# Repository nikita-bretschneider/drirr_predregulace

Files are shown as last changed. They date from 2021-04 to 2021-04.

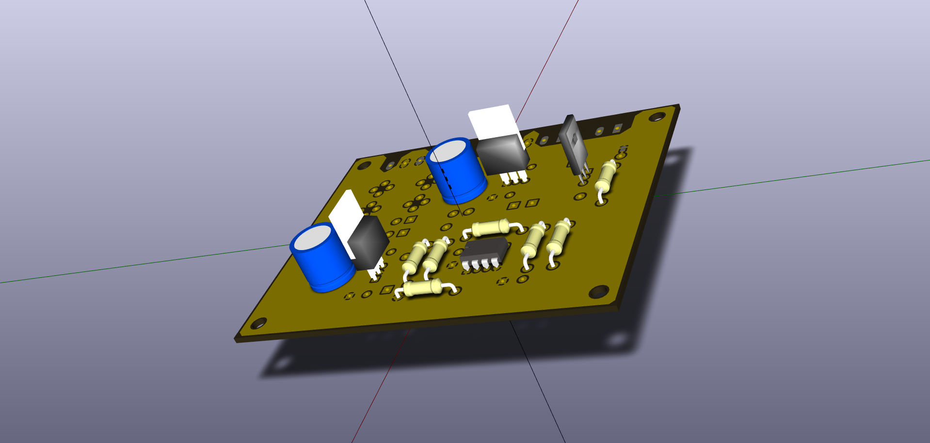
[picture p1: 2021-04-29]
3D/drirr_predreg1.png

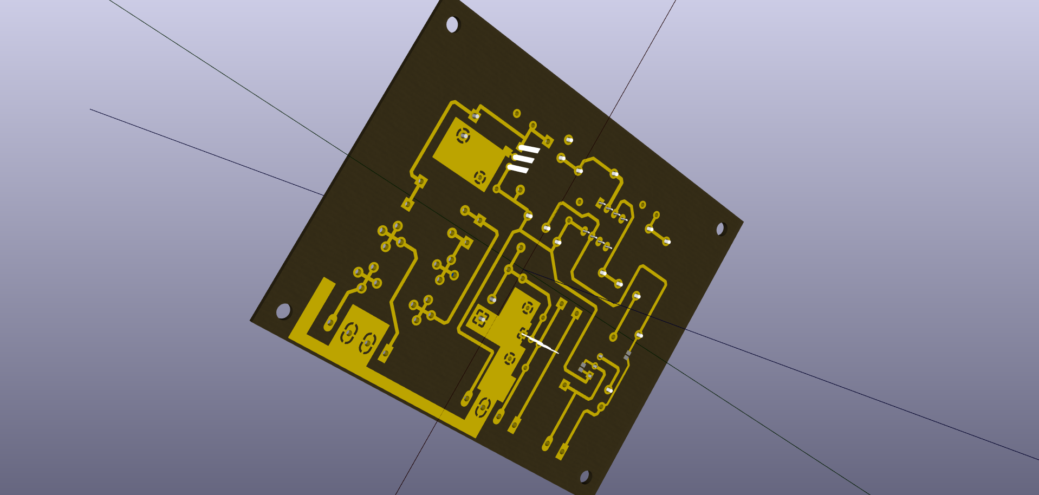
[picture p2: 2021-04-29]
3D/drirr_predreg4.png

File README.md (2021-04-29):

# Poznámky k návrhu desky skokové předregulace

## Změny v konstrukci

Konstrukce není moje. Hodnoty součástek jsou uvedeny pouze tam, kde byly známy (platí pro schéma i silkscreeny). Jediná konstrukční změna je přidání tranzistoru *Q1*, protože proudová zatížitelnost výstupu *LM311* je pouze *50mA*, což stačí na malé relé, avšak chci otevřít možnost použít automobilní relé, jehož pozitivní vlastností je že se nerozteče při trvalém sepnutí. Bohužel si dokáže vzít až *140mA*. PNP tranzistor používám z toho důvodu, aby nebylo nutno měnit logiku spínání. *LM311* sama o sobě spíná v záporném pólu, pokud se aktivuje spínání tranzistorem, spíná se v kladném pólu, vlastní *LM311* spíná pouze bázový proud tranzistoru *Q1*. Použití tohoto tranzistoru je optional a konfiguruje se při osazení propojkami *J4*, *J5* a *J6*. Původní zapojení, tj. bez tranzistoru *Q1*, se aktivuje neosazením *Q1* a *R6*, dále se spojí *J5* a *J6*. Propojka *J4* zůstává rozpojená. Pro použití tranzistoru *Q1* (například při použití automobilního relé) se osadí *R6*, *Q1* a propojí se propojka *J4*. Propojky *J5* a *J6* zůstávají rozpojené.

## Použití pojmenovaných signálů a propojovací definice

Použití pojmenovaných signálů umožňuje rozdělit schéma do funkčních bloků a tak jej zpřehlednit. Separátní definice připojovacích míst k signálům umožňuje snadno měnit pinout jednotlivých konektorů s ohledem na situaci na desce, neb docházelo k optimalizaci na snadnou výrobu a minimální cenu desky. Dále takový postup vytváří přehledný pinout všech použitých konektorů na jediném místě dokumentace, což opět poslouží přehlednosti.

## Vlastní návrh desky, možné problémy, prokovy

Vlastní návrh desky je proveden tak, aby byl výrobně jednoduchý. Desku lze nechat vyrobit jak s prokovy tak bez nich. V obou případech lze za slabé místo považovat kondenzátory *C1* a *C2*, kde je jeden z pólů přístupný do rozlité země (vedení *ACS0*) pouze přes prokov. Vzhledem k zátěži celého pomocného zdroje řádově ve stovkách mA (a z toho plynoucích cirkulačních proudů maximálně ve stovkách mA) to nepovažuji za problém. Větší problém nastává při pájení *C1* a *C2* do desky bez prokovů, kde nelze pájet z horní strany kvůli překrytí vrstvý pouzdrem součástky. Pro tento případ je na spodní straně připravena rozlitá plocha mědi, kdy lze provést propojení s vrchní stranou (stranou součástek) pomocí vývodů jiných součástek, případně na vhodném místě navrtat via.

Desku lze též vyrobit svépomocí, kdy se strana spojů vyrobí například metodou *toner transfer*, přičemž horní strana obsahuje toliko rozlitou měď (s vyjímkou jednoho jumperu, který lze ignorovat, viz níže), čili před leptáním se vykryjí problematická místa (pod pojistkami a pod částmi konektorů) lakýrnickou páskou, celou horní strana se poté přestříká leptuvzdorným lakem a po zaschnutí se odstraní lakýrnická páska. Pro spodní stranu se použije buď metoda toner transfer, nebo fotocesta. V případě toner transferu doporučuji začít spodní stranou, v případě fotocesty doporučuji obrácený postup.  Po odleptání a odvrtání ze spodní strany se z horní  strany následně odstraní měděná plocha v okolí děr buď odfrézováním, nebo zcela jednoduše pomocí mělkého odvrtání tlustým vrtákem. Neodvrtávají se místa, kde je součástka spojena se zemní plochou. V těchto místech se potom pájí z obou stran. Problémem jednoduché výroby je jumper *J4*, který  je ze stramy součástek a při prostém ponechání měděné vrstvy jednoduše nebude existovat. Nepovažuji to však za problém, protože konfigurace se provádí při osazení a později ji již není možné změnit, čili pokud se osazuje *Q1*, potom se neodfrézuje/neodvrtá měděná vrstva kolem anody *D8* a tato se připájí z obou stran. *J6* a *J5* se potom neosazuje. V opačném případě se okolí anody *D8* odfrézuje, *Q1* a *R6* se neosadí, *D8* se zapájí jen z jedné strany a propojí se *J6* a *J5*.

## Proč není na desce relé

Protože otevřenost variabilitě, protože míním použít automobilní relé, které má vlastní držák a vývody na fastonech, v neposlední řadě proto, že se tím zmenší deska. Navíc to vytváří určitou variabilitu v zapojení předregulace, tj. lze například přepínat mezi dvoucestným usměrněním a násobičem, což otevírá možnost použít transformátor, který náhodou máte, namísto nákupu nějakého konkrétního. Celá deska je navrhovaná s ohledem na maximální možnou variabilitu, je zcela nevhodná pro seriovou výrobu včetně maloseriové, takže je pochopitelně nevhodná i pro strojové osazení.

## Proč se používají svorkovnice

V původní konstrukci byly fastony a osobně v nich vidím problém. Ten konektor chce značnou sílu pro zapojení i vypojení, přičemž tato deska byla navrhovaná nejen na maximální variabilitu, ale také na možnost snadné výroby, do které musím bohužel zahrnout nejen pochybné lamináty, ale též kuprokart a jiné hrůzy. Kombinace kuprokartu a fastonu znamená zlomenou desku. Spolehlivě. Svorkovnice ale funguje, protože se na desku příliš netlačí. Pochopitelně na jejím místě lze osadit víceméně leccos, co roztečí odpovídá. Svorkovnice jsou na desce dvě čtyřpólové a jedna dvoupólová. Spojit je všechny do jedné velké svorkovnice není dobrý nápad, toner transfer občas způsobí mírné ujetí rozměrů, což by pro tak velký pevný kus bylo fatální. Svorkovice je tedy rozdělena na tři logické části — propojení s řídící deskou zdroje, čili pomocné napájení *±12V* a *sense* vstup, svorkovnici pro připojení cívky relé a svorkovnici pro připojení pomocného transformátoru. Tato je zvolena čtyřpinová ze dvou důvodů. Především dvoupinové svorkovnice lze stohovat na čtyřpólové, takže tato volba znamená, že koupíte pět dvoupólových (a dostanete množstevní slevu, což by vás při nákupu jedné třípólové nepotkalo), dále transformátor může mít dvě oddělená sekundární vinutí, proto je střed vyveden dvakrát.

## Použití pomocného transformátoru s jediným sekundárním vinutím

Pokud máte pomocný transformátor jen s jediným vinutím bez vyvedeného středu, neosadí se *F1*, *D1*, *D4* a polovina svorkovnice *J3*. Dále je nutno zvětšit kapacity *C1* a *C2* na minimálně dvojnásobek.Transformátor potom pracuje v lichých půlvlnách do jedné větve a v sudých do druhé. Toto řešení však příliš nedoporučuji.

## Závěr, varování

Konstrukce není moje, desky nevyrábím, pokud si někde chcete zadat výrobu, je to váš problém, odmítám za to nést jakoukoliv odpovědnost. Chyby se stávají, to je realita. Vše si důkladně zkontrolujte a rozmyslete před tím, než začnete desku vyrábět.

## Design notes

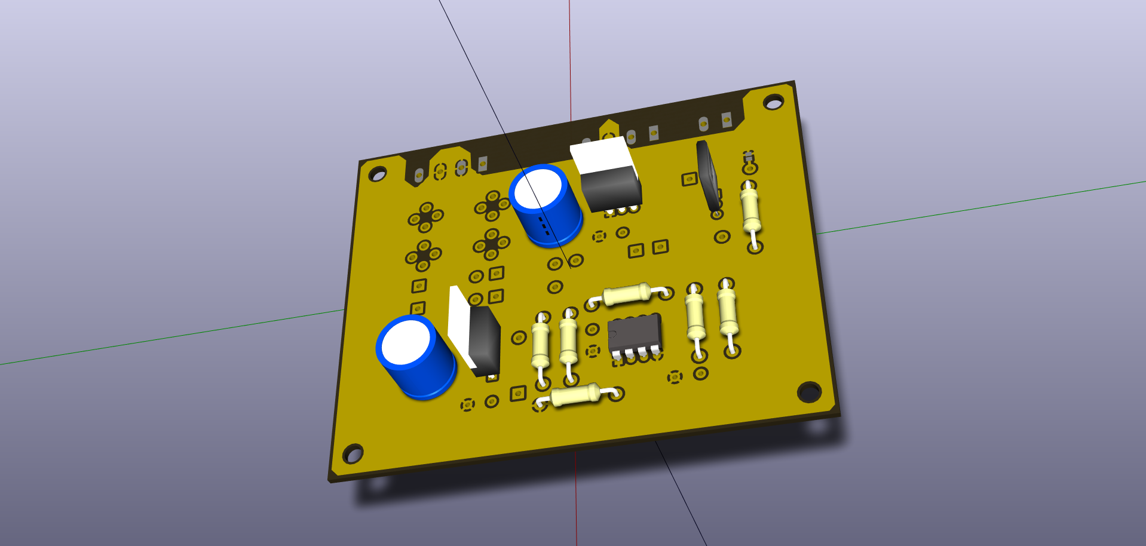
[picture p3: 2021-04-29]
3D/drirr_predreg2.png

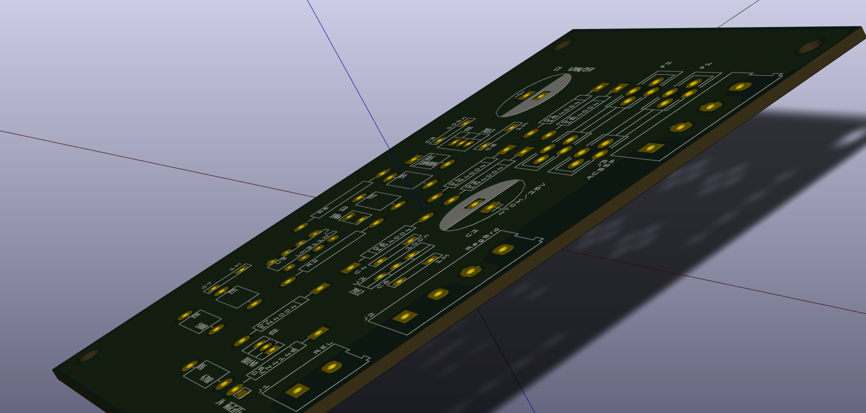
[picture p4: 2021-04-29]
3D/drirr_predregA.png

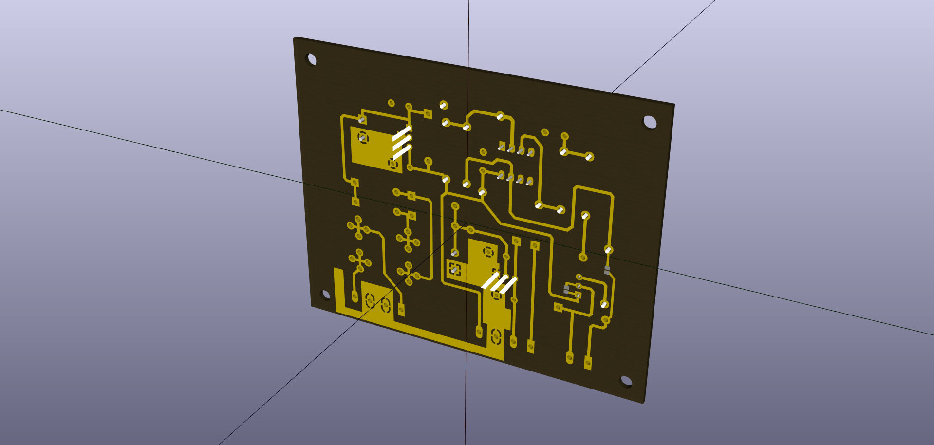
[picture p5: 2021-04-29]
3D/drirr_predreg3.png

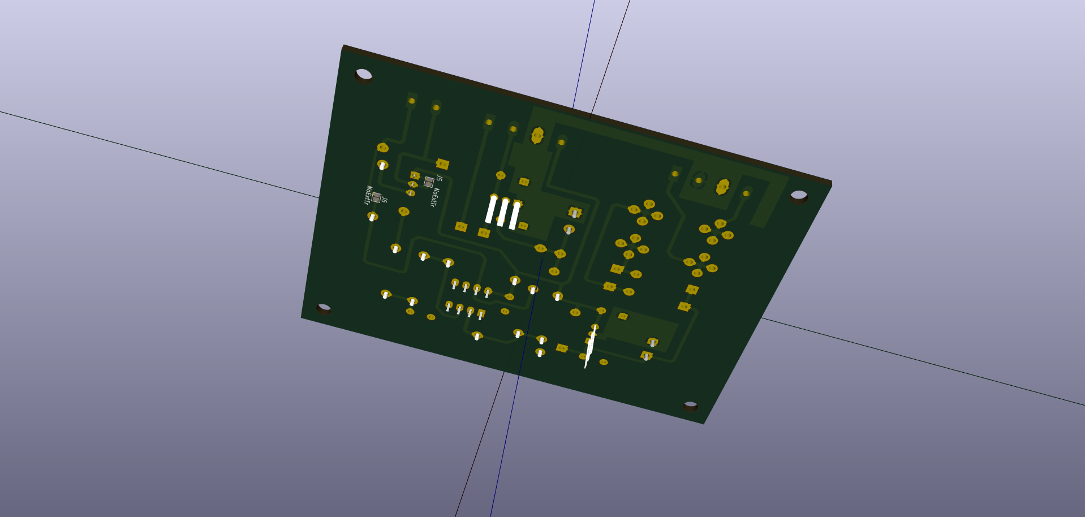
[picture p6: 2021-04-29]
3D/drirr_predreg7.png

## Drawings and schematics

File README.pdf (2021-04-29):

# Poznámky k návrhu desky skokové předregulace

# Změny v konstrukci

Konstrukce není moje. Hodnoty součástek jsou uvedeny pouze tam, kde byly známy (platí pro schéma i silkscreeny). Jediná konstrukční změna je přidání tranzistoru Q1, protože proudová zatížitelnost výstupu LM311 je pouze 50mA, což stačí na malé relé, avšak chci otevřít možnost použít automobilní relé, jehož pozitivní vlastností je že se nerozteče při trvalém sepnutí. Bohužel si dokáže vzít až 140mA. PNP tranzistor používám z toho důvodu, aby nebylo nutno měnit logiku spínání. LM311 sama o sobě spíná v záporném pólu, pokud se aktivuje spínání tranzistorem, spíná se v kladném pólu, vlastní LM311 spíná pouze bázový proud tranzistoru Q1. Použití tohoto tranzistoru je optional a konfiguruje se při osazení propojkami J4, J5 a J6. Původní zapojení, tj. bez tranzistoru Q1, se aktivuje neosazením Q1 a R6, dále se spojí J5 a J6. Propojka J4 zůstává rozpojená. Pro použití tranzistoru Q1 (například při použití automobilního relé) se osadí R6, Q1 a propojí se propojka J4. Propojky J5 a J6 zůstávají rozpojené.

# Použití pojmenovaných signálů a propojovací definice

Použití pojmenovaných signálů umožňuje rozdělit schéma do funkčních bloků a tak jej zpřehlednit. Separátní definice připojovacích míst k signálům umožňuje snadno měnit pinout jednotlivých konektorů s ohledem na situaci na desce, neb docházelo k optimalizaci na snadnou výrobu a minimální cenu desky. Dále takový postup vytváří přehledný pinout všech použitých konektorů na jediném místě dokumentace, což opět poslouží přehlednosti.

# Vlastní návrh desky, možné problémy, prokovy

Vlastní návrh desky je proveden tak, aby byl výrobně jednoduchý. Desku lze nechat vyrobit jak s prokovy tak bez nich. V obou případech lze za slabé místo považovat kondenzátory C1 a C2, kde je jeden z pólů přístupný do rozlité země (vedení ACS0) pouze přes prokov. Vzhledem k zátěži celého pomocného zdroje řádově ve stovkách mA (a z toho plynoucích cirkulačních proudů maximálně ve stovkách mA) to nepovažuji za problém. Větší problém nastává při pájení C1 a C2 do desky bez prokovů, kde nelze pájet z horní strany kvůli překrytí vrstvý pouzdrem součástky. Pro tento případ je na spodní straně připravena rozlitá plocha mědi, kdy lze provést propojení s vrchní stranou (stranou součástek) pomocí vývodů jiných součástek, případně na vhodném místě navrtat via.

Desku lze též vyrobit svépomocí, kdy se strana spojů vyrobí například metodou toner transfer, přičemž horní strana obsahuje toliko rozlitou měď (s vyjímkou jednoho jumperu, který lze ignorovat, viz níže), čili před leptáním se vykryjí problematická místa (pod pojistkami a pod částmi konektorů) lakýrnickou páskou, celou horní strana se poté přestříká leptuvzdorným lakem a po zaschnutí se odstraní lakýrnická páska. Pro spodní stranu se použije buď metoda toner transfer, nebo fotocesta. V případě toner transferu doporučuji začít spodní stranou, v případě fotocesty doporučuji obrácený postup. Po odleptání a odvrtání ze spodní strany se z horní strany následně odstraní měděná plocha v okolí děr buď odfrézováním, nebo zcela jednoduše pomocí mělkého odvrtání tlustým vrtákem. Neodvrtávají se místa, kde je součástka spojena se zemní plochou. V těchto místech se potom pájí z obou stran. Problémem jednoduché výroby je jumper J4, který je ze stramy součástek a při prostém ponechání měděné vrstvy jednoduše nebude existovat. Nepovažuji to však za problém, protože konfigurace se provádí při osazení a později ji již není možné změnit, čili pokud se osazuje Q1, potom se neodfrézuje/neodvrtá měděná vrstva kolem anody D8 a tato se připájí z obou stran. J6 a J5 se potom neosazuje. V opačném případě se okolí anody D8 odfrézuje, Q1 a R6 se neosadí, D8 se zapájí jen z jedné strany a propojí se J6 a J5.

# Proč není na desce relé

Protože otevřenost variabilitě, protože míním použít automobilní relé, které má vlastní držák a vývody na fastonech, v neposlední řadě proto, že se tím zmenší deska. Navíc to vytváří určitou variabilitu v zapojení předregulace, tj. lze například přepínat mezi dvoucestným usměrněním a násobičem, což otevírá možnost použít transformátor, který náhodou máte, namísto nákupu nějakého konkrétního. Celá deska je navrhovaná s ohledem na maximální možnou variabilitu, je zcela nevhodná pro seriovou výrobu včetně maloseriové, takže je pochopitelně nevhodná i pro strojové osazení.
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

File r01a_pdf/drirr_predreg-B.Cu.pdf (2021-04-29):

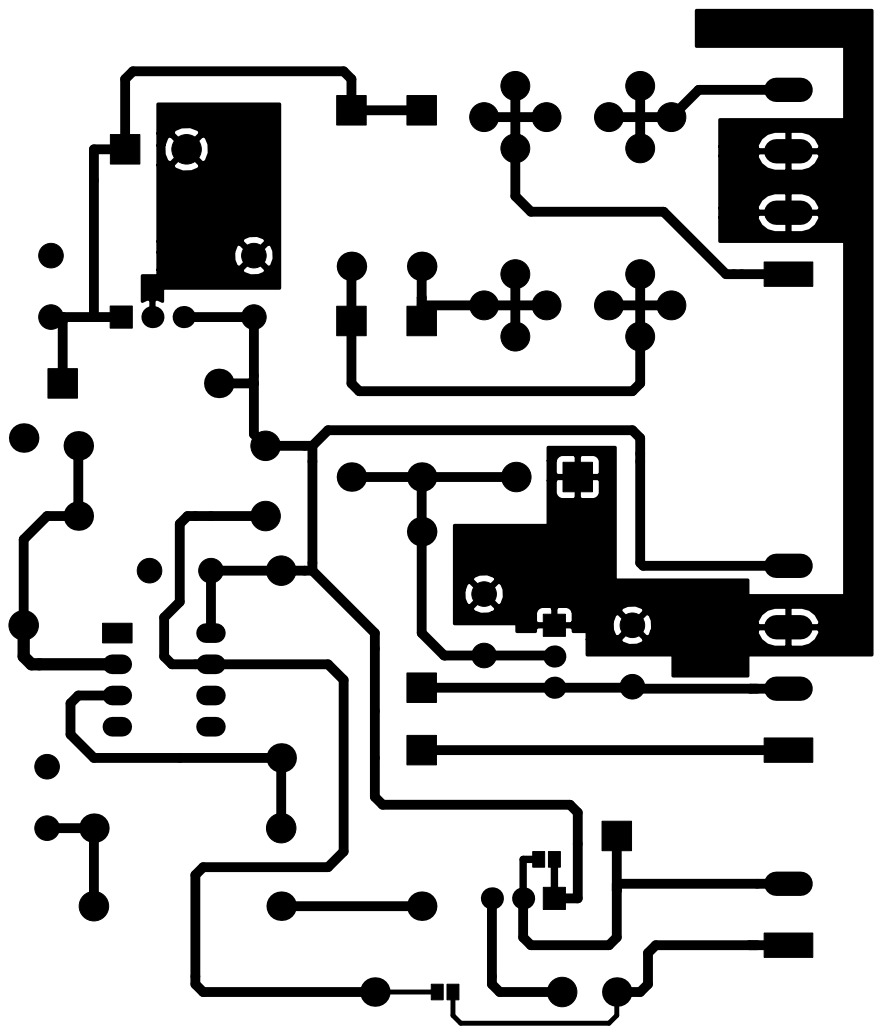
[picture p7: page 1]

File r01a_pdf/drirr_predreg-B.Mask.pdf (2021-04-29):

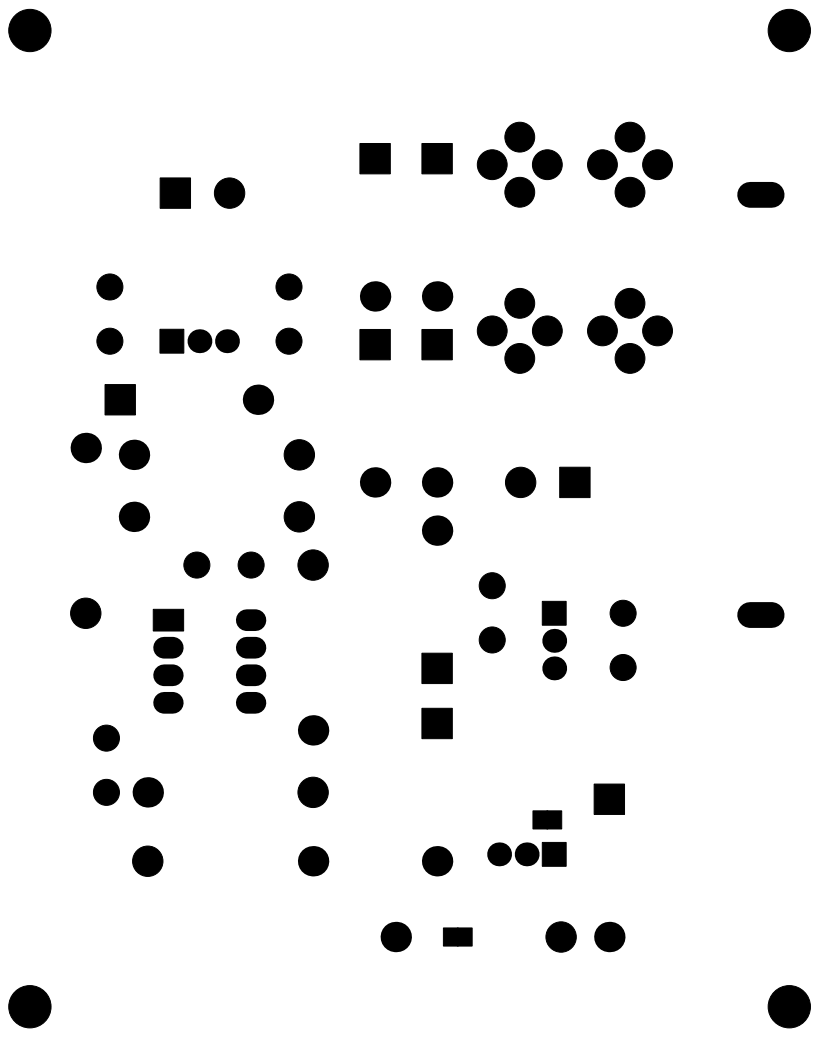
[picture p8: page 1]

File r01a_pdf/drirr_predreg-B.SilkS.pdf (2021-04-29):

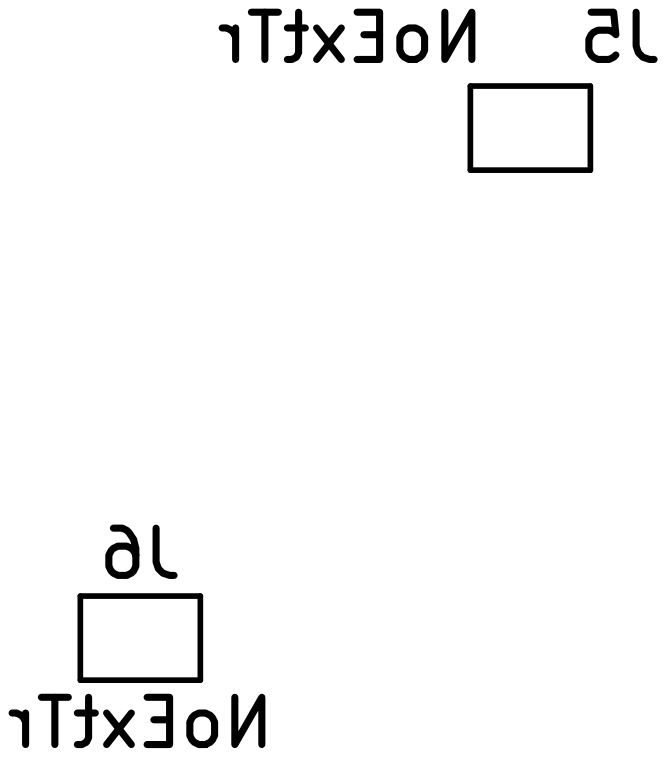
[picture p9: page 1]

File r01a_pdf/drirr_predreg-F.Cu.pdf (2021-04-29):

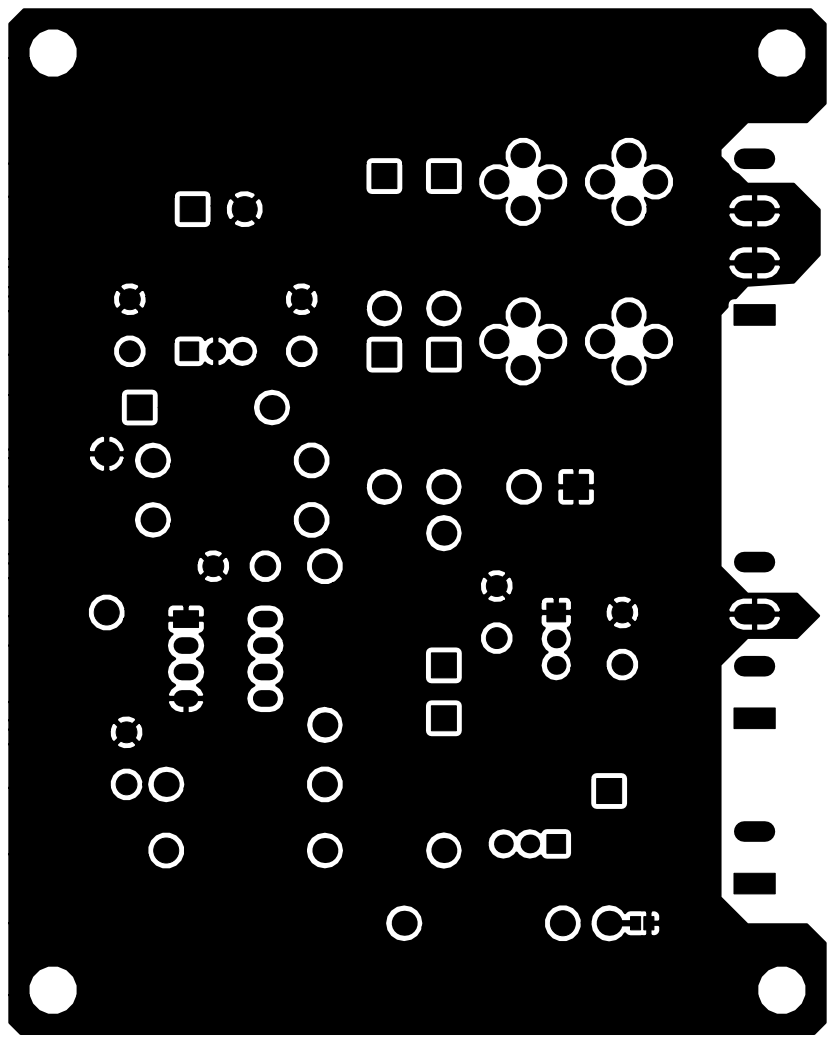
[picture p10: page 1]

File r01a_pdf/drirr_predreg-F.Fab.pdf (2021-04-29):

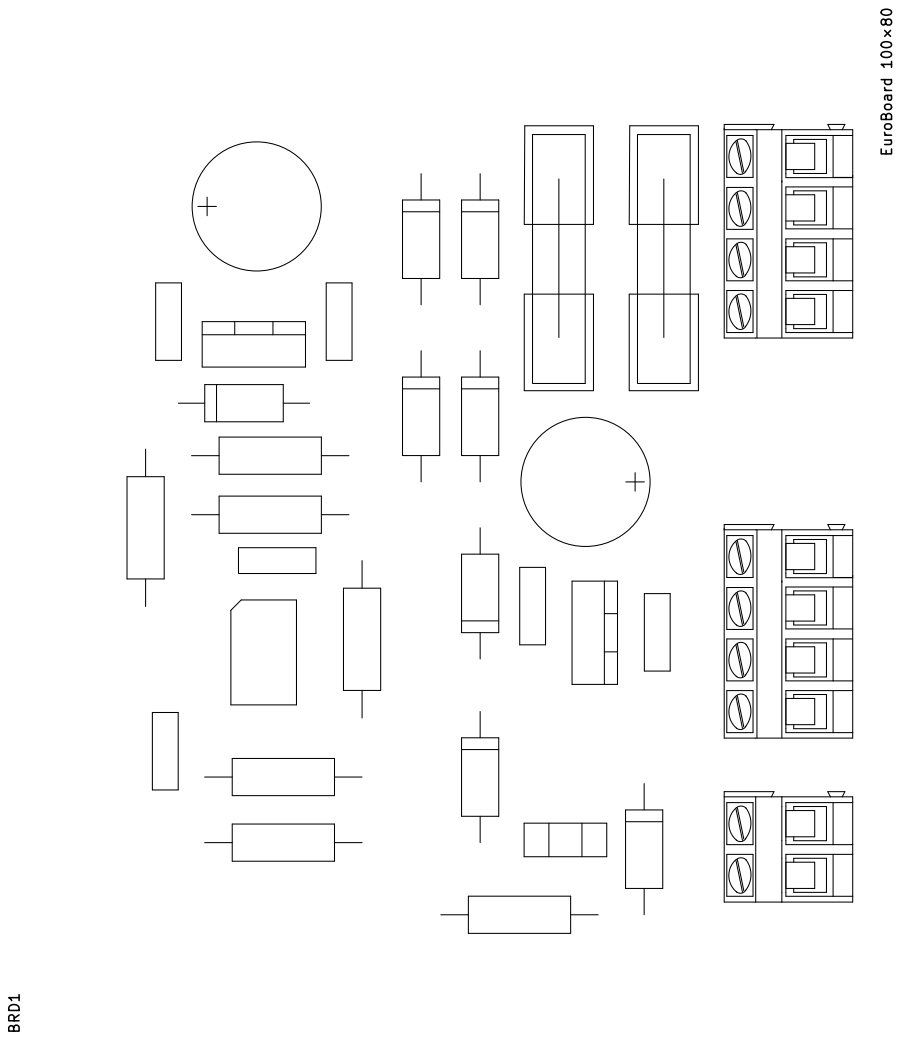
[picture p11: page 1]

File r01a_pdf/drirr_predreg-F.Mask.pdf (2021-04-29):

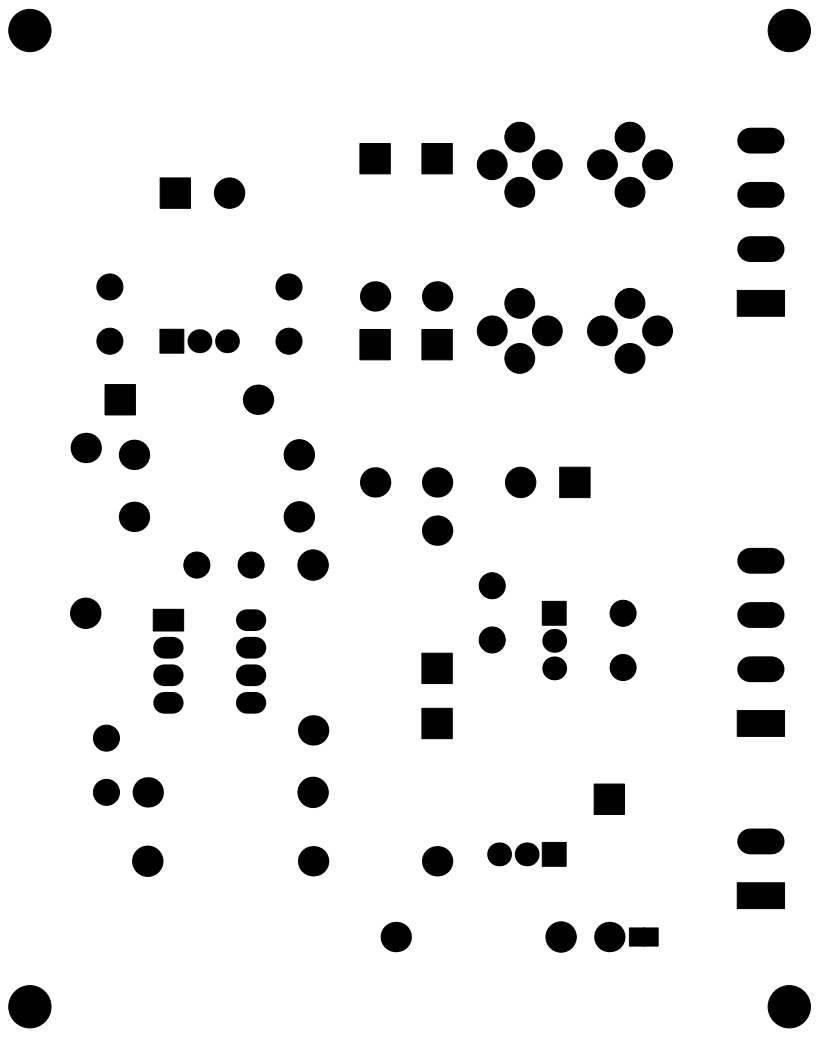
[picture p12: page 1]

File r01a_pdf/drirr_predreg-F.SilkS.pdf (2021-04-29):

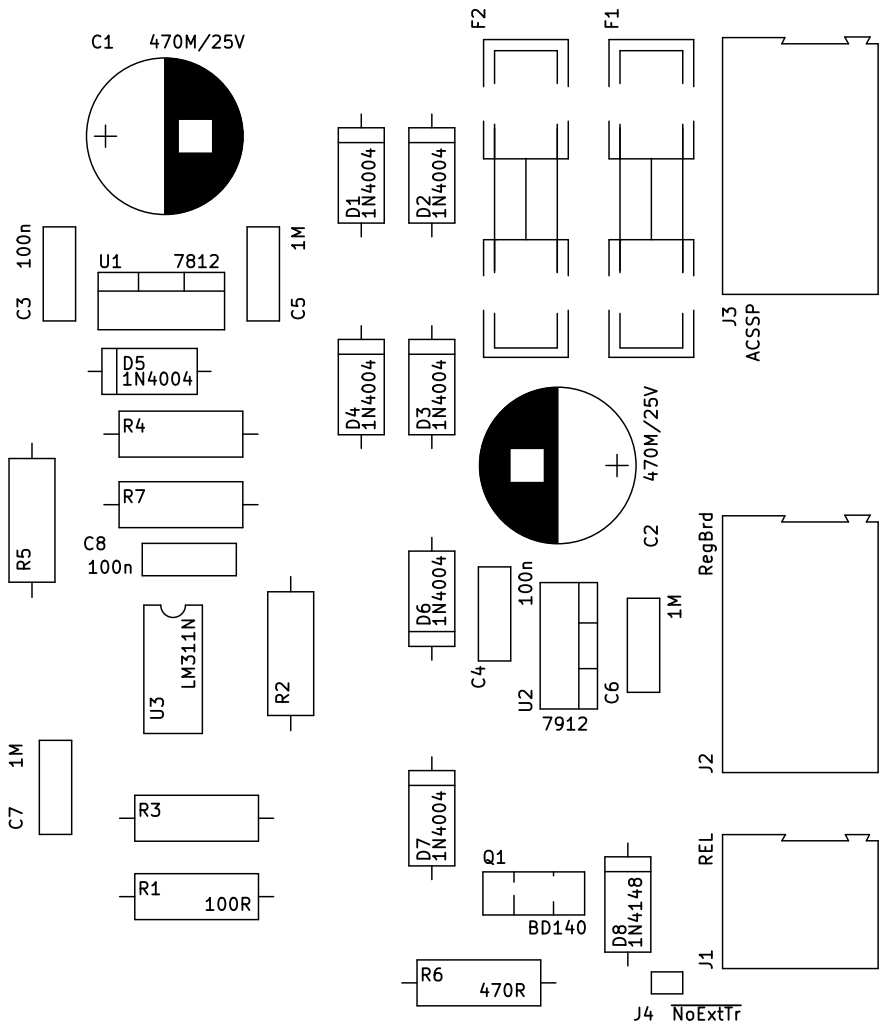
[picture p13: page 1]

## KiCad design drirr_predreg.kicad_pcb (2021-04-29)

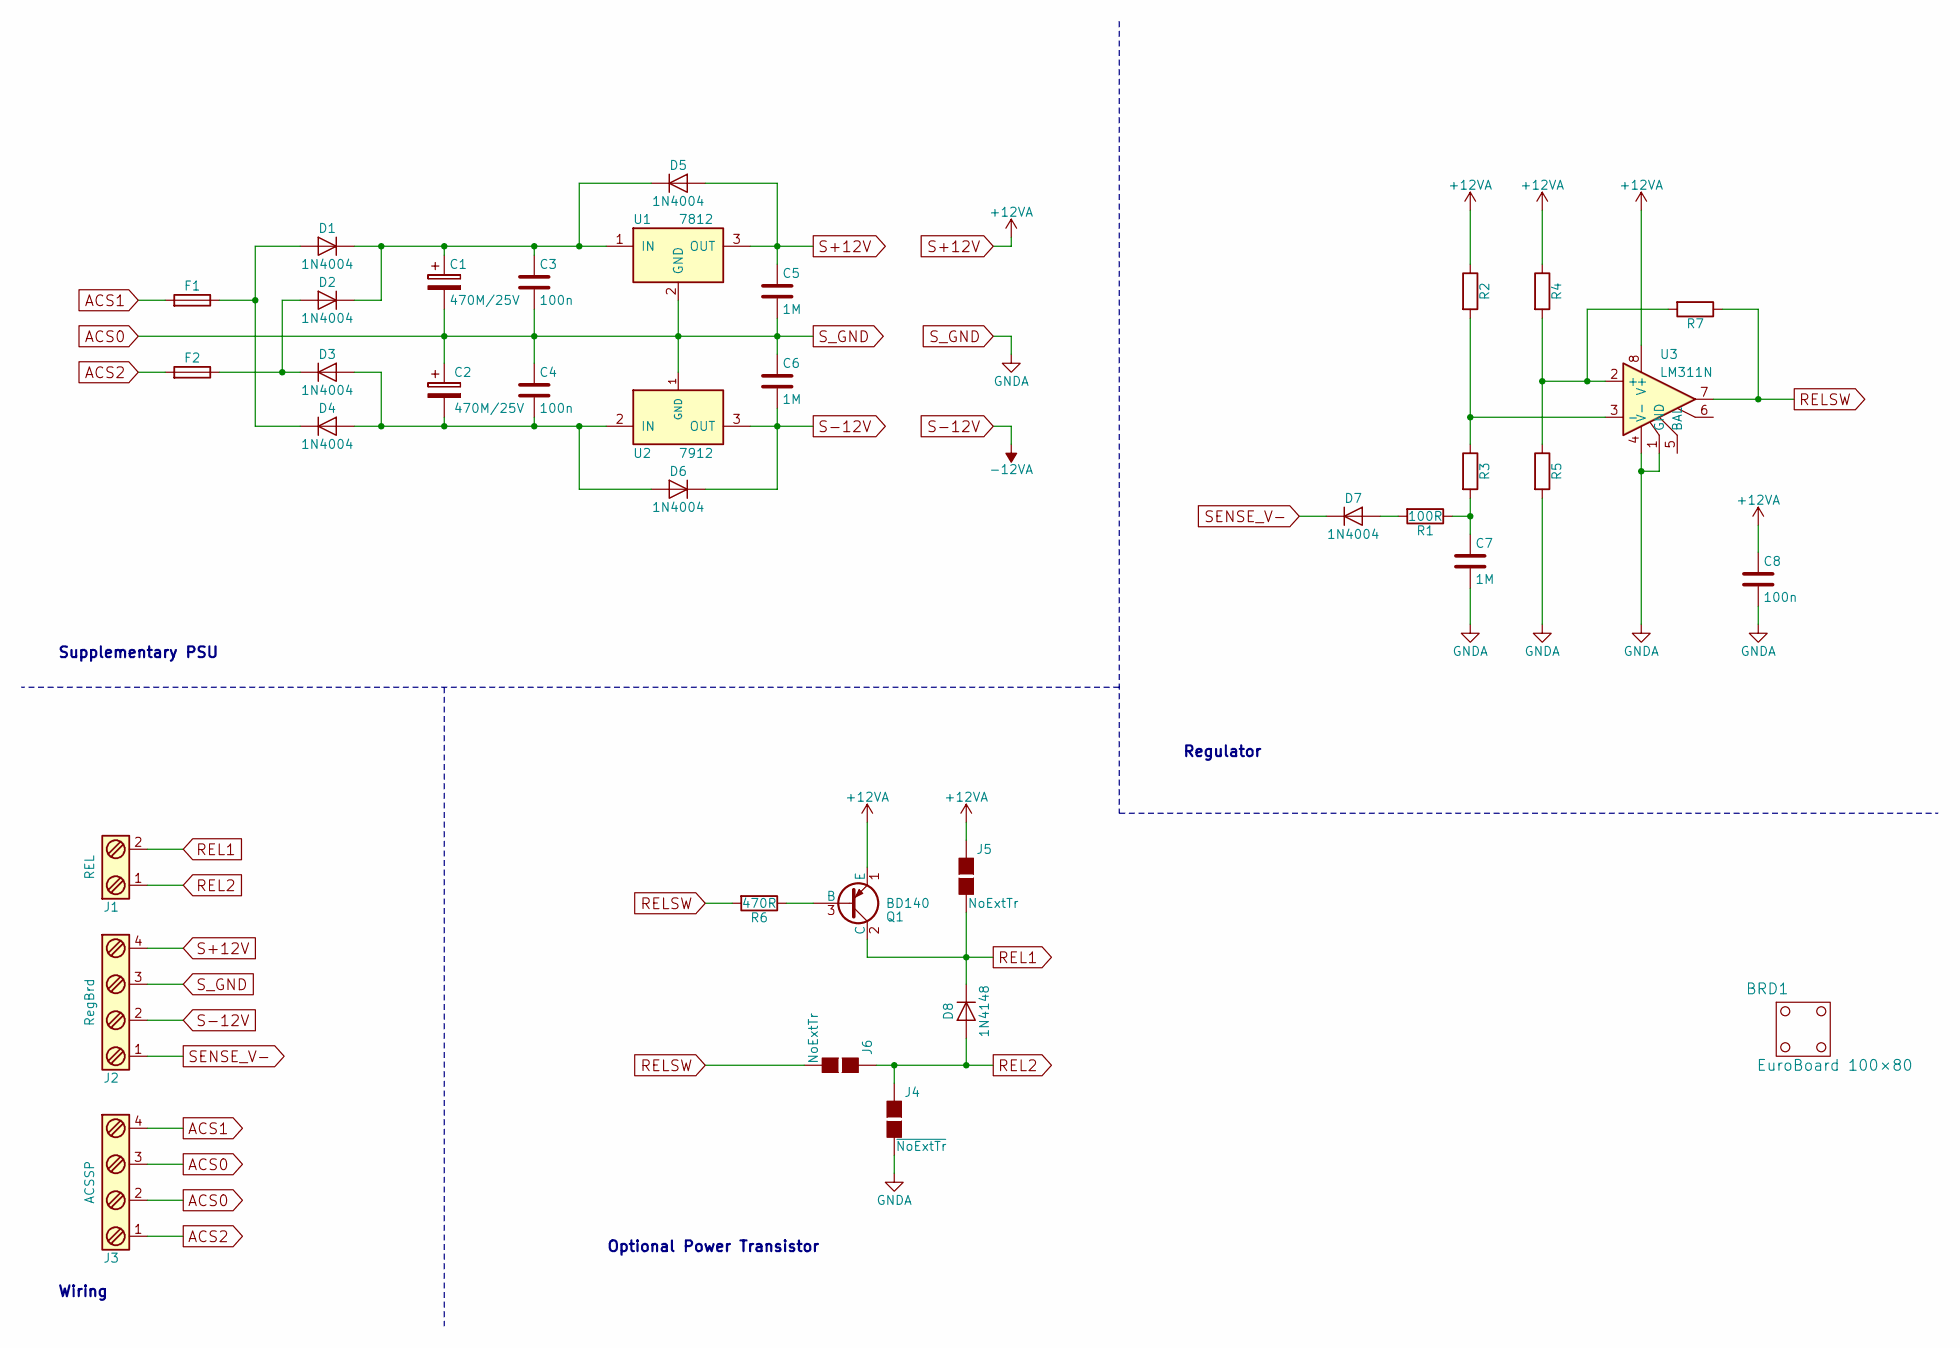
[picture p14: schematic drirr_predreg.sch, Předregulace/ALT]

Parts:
BRD1: EuroBoard 100×80; EuroBoard_halb_Type-I_100mmX80mm_holes
C1, C2: 470M/25V; CP_Radial_D12.5mm_P5.00mm
C3, C4, C8: 100n; C_Disc_D7.5mm_W2.5mm_P5.00mm
C5, C6, C7: 1M; C_Disc_D7.5mm_W2.5mm_P5.00mm
D1, D2, D3, D4, D5, D6, D7: 1N4004; D_DO-15_P12.70mm_Horizontal
D8: 1N4148; D_DO-15_P12.70mm_Horizontal
F1, F2: Fuse; Fuseholder5x20_horiz_open_universal_Type-III
J1: REL; AK300-2
J2: RegBrd; AK300-4
J3: ACSSP; AK300-4
J4: ~NoExtTr; GS2
J5, J6: NoExtTr; GS2
Q1: BD140; TO-126_Vertical
R1: 100R; R_Axial_DIN0411_L9.9mm_D3.6mm_P15.24mm_Horizontal
R2, R3, R4, R5, R7: R; R_Axial_DIN0411_L9.9mm_D3.6mm_P15.24mm_Horizontal
R6: 470R; R_Axial_DIN0411_L9.9mm_D3.6mm_P15.24mm_Horizontal
U1: 7812; TO-220_Vertical
U2: 7912; TO-220_Vertical
U3: LM311N; DIP-8_W7.62mm_LongPads

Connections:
ACS0: C1.2, C2.1, C3.2, C4.1, C5.2, C6.1, C7.2, C8.2, J2.3, J3.2, J3.3, J4.2 (G2), R5.2, U1.2 (GND), U2.1 (GND), U3.1 (GND), U3.4 (V-)
ACS1: F1.2, J3.4
ACS2: F2.2, J3.1
unnamed: C1.1, C3.1, D1.1 (K), D2.1 (K), D5.1 (K), U1.1 (IN)
unnamed: C2.2, C4.2, D3.2 (A), D4.2 (A), D6.2 (A), U2.2 (IN)
unnamed: C7.1, R1.1, R3.2
unnamed: D1.2 (A), D4.1 (K), F1.1
unnamed: D2.2 (A), D3.1 (K), F2.1
unnamed: D7.2 (A), R1.2
unnamed: Q1.3 (B), R6.1
unnamed: R2.2, R3.1, U3.3 (-)
unnamed: R4.2, R5.1, R7.2, U3.2 (+)
REL1: D8.1 (K), J1.2, J5.2 (G2), Q1.2 (C)
REL2: D8.2 (A), J1.1, J4.1 (G1), J6.1 (G1)
RELSW: J6.2 (G2), R6.2, R7.1, U3.7
S+12V: C5.1, C8.1, D5.2 (A), J2.4, J5.1 (G1), Q1.1 (E), R2.1, R4.1, U1.3 (OUT), U3.8 (V+)
S-12V: C6.2, D6.1 (K), J2.2, U2.3 (OUT)
SENSE_V-: D7.1 (K), J2.1

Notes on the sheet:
Supplementary PSU
Wiring
Regulator
Optional Power Transistor

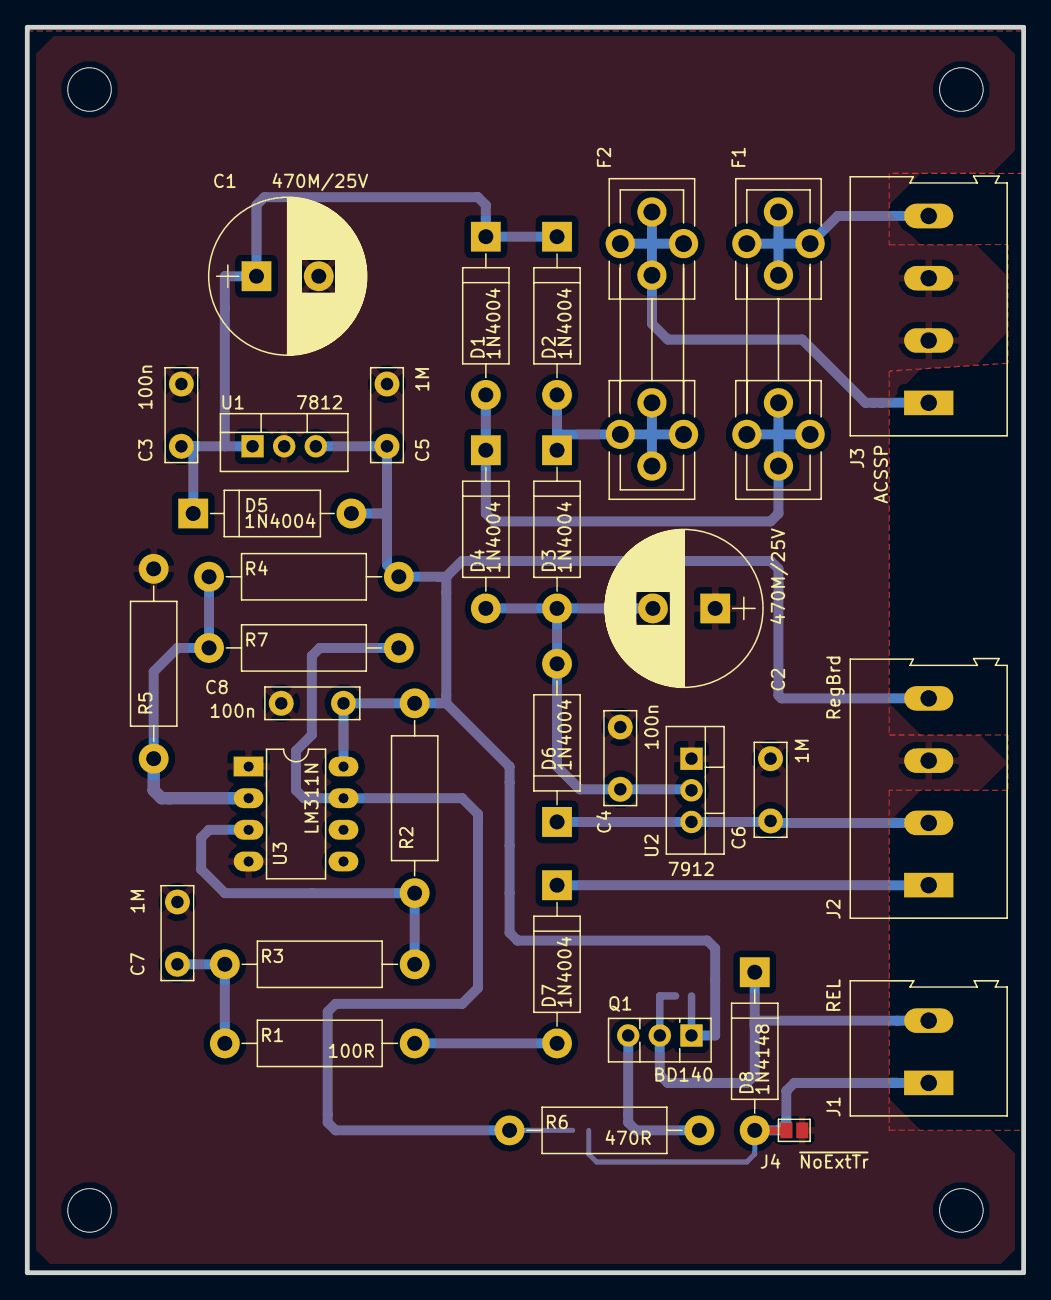
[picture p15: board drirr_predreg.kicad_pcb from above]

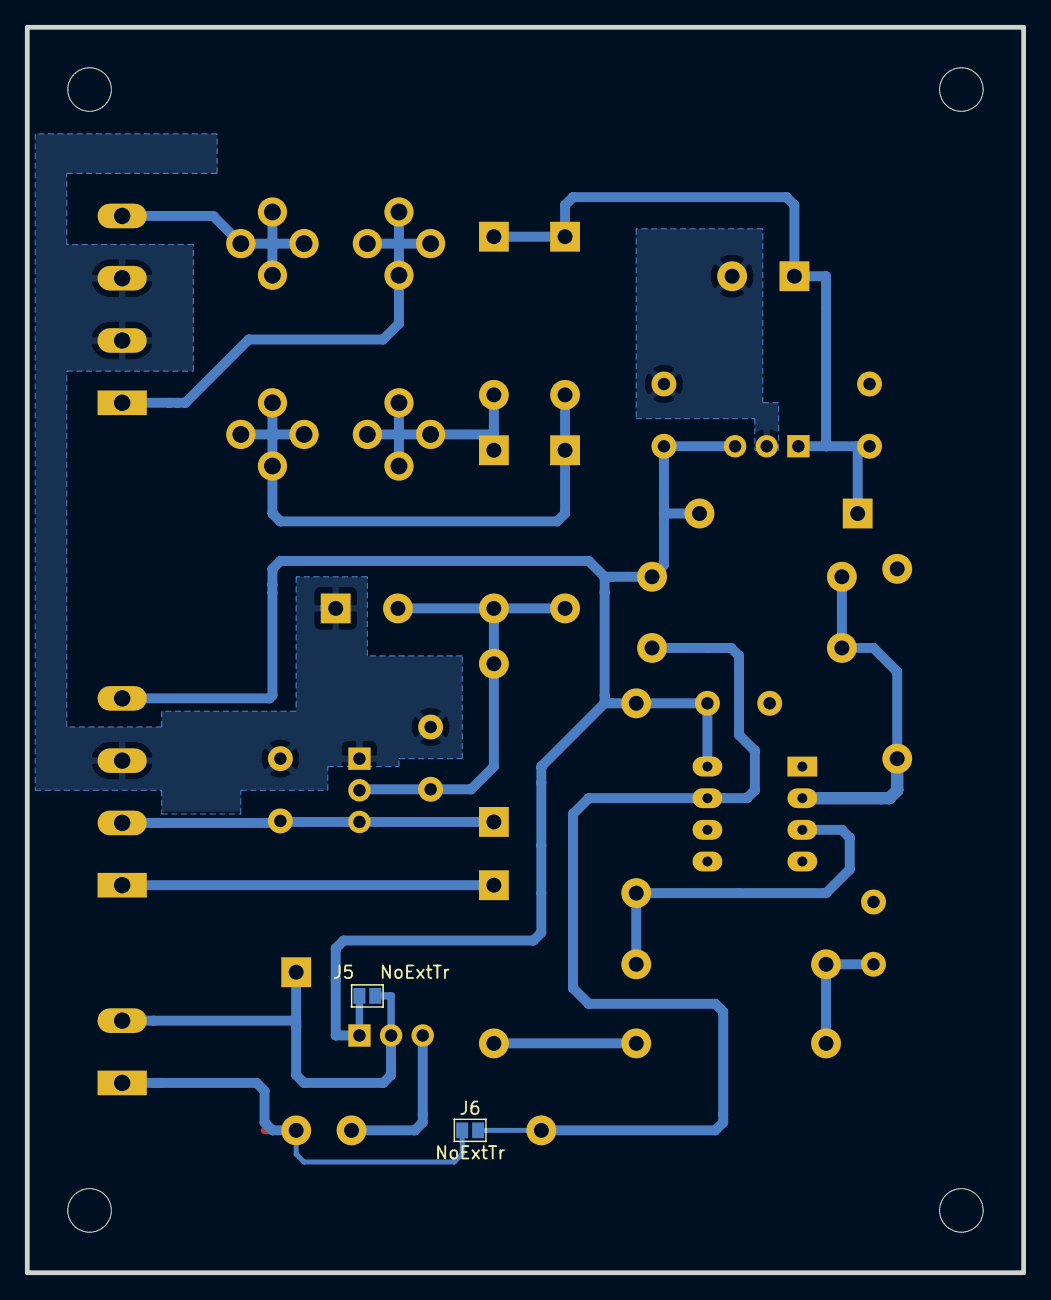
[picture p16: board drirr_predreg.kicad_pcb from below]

Board: 2 copper layers, 80.0 x 100.0 mm, 36 parts (2 on the bottom side), 18 nets.
